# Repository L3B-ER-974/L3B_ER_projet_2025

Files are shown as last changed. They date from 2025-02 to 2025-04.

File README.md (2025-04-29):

# L3B_ER_projet_2025

Le but de notre projet est d'équipé le navire "SARL Réunion Formation Plongée" d'un ensemble d’appareils et de capteurs à la norme NMEA2000.

Projet2025

## Description du module et attendu final

Mon module c'est une carte avec un écran monté dessus relier avec un microcontroleur (ATMEGA328-16AU), un programmateur (HE10_6), une alimentation XL1509-5.0 (ce composant là va me permettre d'adapter le courant d'entré en 5V pour toute la carte), d'un MCP2551 et d'un MCP2515, d'un GX12 (c'est là que va arrivé les informations des capteurs), d'un AMS1117-3.3 (ce composant là c'est pour régulé la tension à 3,3 V pour l'écran), un connecteur embase droite pour voir les trames et enfin des diodes électroluminécantes (XL-3216SURC) pour voir les communications TX, RX et l'alimentation si ils sont tous bien connectés. Le MCP2551 et le MCP2515 vont tout les deux me permettre d'assurer la communication entre le microcontroleur et les capteurs et de garder temporairement les données des capteurs.

Ce qui est attendu au final, c'est que je dois concevoir une carte avec les composants marqués au-dessus, un écran multifonctions qui gère par derrière les trames NMEA2000 des capteurs et qui les affiches en clair sur l'écran.

<ins> **Exemple d'un écran multifonctions avec les relevés des capteurs  :**</ins>

   

<ins> **Exemple de carte à fabriqué :**</ins>



## Description des grandeurs d'entrée et de sortie 

Ma maquette, ce qu'il fait, c'est qu'il va recevoir les trames NMEA2000 des différents capteurs à l'entrée (Ils vont tous passer par le GX12), ils vont ensuite être filtrés et traités par mes composants MCP2515 et MCP2555. Ensuite, ces mêmes composants vont assurer la passerelle entre le microcontrôleur et les composants (BUS SPI). Ensuite, le microcontrôleur traite les données des différents capteurs et les envoie ensuite sous format de texte les valeurs des différents capteurs sur un écran LCD SPI (Un programme sera mis dans le microcontroleur pour traité les données des capteurs) .

## Description des composants constitutifs de l'unité 

Ecran LCD "SKU MAR2406 driver ILI9341" : 
 
 - Taille écran : 2.4 pouces (6,096 cm en diagonal )
 - Résolution : 320*240 pixel
 - Couleur : RGB 65k color
 - Communication : BUS SPI

Microprocesseur "ATMEGA328-16AU": 
 
 - Alimentation : 1.8 - 5.5 V
 - Plage de fréquence : 0 - 20 MHz
 - programmable en série USART
 - Possédent 32 broches au total
 - Limitation courant : 200 mA
 - Possédent l'interface SPI et 2-wire
 - Accepte jusqu'à 32 kbit les prè-programmes
 - Possédent une mémoire EEPROM qui garde l'information jusqu'a 1kbit lorsque la carte est éteint.

Composant "MCP2515" : 

 - Communication : CANH et CANL
 - Alimentation : 2.7 V - 5.5 V
 - Plage de température : -40 °C à + 85 °C
 - Interface SPI cadencé à 10 MHz

Composant "MCP2551" :
 
 - Communication : CANH et CANL
 - Alimentation : 4.5V - 5.5V
 - Tension continue pour CANH et CANL entre : -42 V et + 42 V
 - Plage de température : -55 °C et + 150 °C

Composant "XL1509-5.0" :

 -Tension de sortie régulé à : 5V (valeur typique)
 -Tension d'entré accepté : 4.5V - 40V
 -Oscillateur de fréquence : 150 khz (valeur typique)
 -Limite de courant : 4 A.

Composant "AMS1117-3.3" : 

- Régule la tension jusqu'à 5 V
- La tension d'entré maximun est 18 V
- La plage de température est compris entre -65 °C à 150 °C

Le protocole qui est utilisé c'est le protocole SIMNET et pour la communication c'est le BUS CAN. 

## Les diagrammes 

<ins> **Diagramme de cas d'utilisation :**</ins>

Diagramme_de_cas_utilisation

<ins> **Diagramme d'éxigence :**</ins>

Diagramme_exigence_Jean

<ins> **Diagramme de bloc interne :**</ins>

Diagramme_de_bloc_interne

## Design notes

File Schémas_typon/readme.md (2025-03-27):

# Description des composants utilisés

- [x] Réalisation du schéma structurel
   - Justification du choix des composants principaux

ATMEGA328-16AU : Nous avons choisir de prendre un ATMEGA328-16AU car la fréquence que fournit le composant (fournir jusqu'à 20 MHz) permet de faire tourner tout les autres composants. De plus, le composant est capable de gérer le BUS SPI.

XL1509-5.0 : Nous avons choisir ce régulateur de tensions là car la plage qu'on peut fournir à l'entré du composant s'éléve jusqu'à 40 V ce qui est plus convenable. De plus, le composant est capable de réguler la tension jusqu'à 5 V ce qui est convenable pour nos composant qui nécessite justement une plage compris entre 1 V et 5 V. 

AMS1117-3.3 : Nous avons choisir ce régulateur tensions pour l'écran LCD. En effet, nous avons choisir ce régulateur tensions car la tensions nécessaire au fonctionnement de l'écran LCD nécessite une tension de 3,3 V.Donc, aprés que le régulateur XL1509-5.0 est finir de régulé la tensions à 5 V, c'est au tour du composant AMS1117-3.3 de régulé à nouveau la tension à 3.3 V pour l'écran LCD qui ne peut encore là que accepter une tension de 3.3 V. 

MCP2551 : Nous avons choisir ce composant là car il va servir de passerelle entre le contrôleur CAN et le bus CAN, il va convertir les signaux logiques en signaux électriques pour adapter au BUS CAN.   

MCP2515 : Nous avons choisir ce composant là car il va gérer la gestion des messages CAN, filtrer les messages et il communiquera ces messages avec le microcontroleur en SPI. 

LCD3.5 UNO : Alors sur le schéma sctructurel nous avons prévues d'utiliser un écran LCD 2.4 pouces mais nous avons anticipé sur un écran LCD plus grand un 3.5 pouces. Pourquoi on a fait ça ? On a fait ça au cas ou si nous voulons un écran LCD plus grande. Nous avons choisir un LCD 2.4 pouces pour affiché les valeurs des capteurs sur un écran LCD (il va servir d'écran multifonctions). 
   
- [x] Réalisation du typon en double face
  
   - Contraintes de réalisation (dimension, largeur des pistes...)

Les contraintes de réalisation sont : 

  - Les pistes pour les composants d'alimentations qui fournit des tensions haute doivent faire 20mil sinon ils vont brûlé la carte (GX12, XL1509-5.0, les condensateurs et les inductances qui sont relier à ces alimentations ).
  - Les pistes pour le microcontroleur ATMEGA328-16AU doivent avoir une épaisseur de 15mil au maximun.
  - Les pistes doivent pas se croisé.
  - Limiter au maximun les trous sur les cartes (Les Vias).
  - Respecté un espacement entre les pastiles et les pistes qui passent entre les deux.
  - Priorisé les pistes du microcontroleurs en premier et les composants d'alimentations en dernier.
  - Ajouter deux plan de masse un au-dessus et un en-dessous de la carte.
  - Renseigné que la référence des composants (Exemple : R10, C15,U1) et pas le type ou les valeurs des composants (exemple : XL1509-5.0, 150 µF...)  car ce qui est important c'est qu'on voir la référence des composants quand la carte est finir (Voir image ci-dessous).
  - La référence des composants doivent être bien lisible et doivent avoir la même orientation exemple : "si une référence d'un composant est positionné horizontalement alors tout les autres références doivent être positionné pareillement pour facilité la visibilité ".  
  - Mettre les connecteurs au bord de la carte (Salea logic, GX12, ISP-PROG)
  - Il faut limité les angles droits des pistes. 

<ins>Carte de projet croix de pharmacie :</ins> 



Il faut que l'orientation des textes soient tous pareils. 

- [x] Édition des fichiers de constructions Gerber

L'édition qu'il y a eu sont : 
 
 - Les pistes que je devais reposiotionné. (déjà fait)
 - Les références des composants que je devais tous bien orientés. (déjà fait)
 - Les ajouts des plans de masses sur la partie au-dessus et en-dessous de la carte. (déjà fait)

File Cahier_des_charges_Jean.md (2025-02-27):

# L3B_ER_projet_2025

Le but de notre projet est d'équipé le navire "SARL Réunion Formation Plongée" d'un ensemble d’appareils et de capteurs à la norme NMEA2000.

Projet2025

## Description du module et attendu final

Le module que je dois concevoir c'est un écran multifonction qui affiche les mesures de l'anémomètre-girouette (la vitesse du vent ainsi que sa direction), la température, le débit et le niveau d'essence pour le moteur 1, le régime moteur et totalisateur horaire du moteur 2 et enfin la vitesse relative sur l'eau.

Ce qui est attendu au final c'est que je dois concevoir une carte fonctionnel qui affiche les mesures que j'ai cité au-dessus. 

<ins> **Exemple d'écran multifonction avec d'autre mesure  :**</ins>


 
<ins> **Exemple de carte à fabriqué :**</ins>



## Description des grandeurs d'entrée et de sortie 

Alors notre maquette va recevoir à l'entré le bus de données CAN, ensuite, ces données vont être traité par le microcontroleur puis ils vont être affiché par l'afficheur LCD 2.4inch en bus SPI. 

## Description des composants constitutifs de l'unité 

Ecran LCD "SKU MAR2406 driver ILI9341" : 
 
 - Taille écran : 2.4 pouces (6,096 cm en diagonal )
 - Résolution : 320*240 pixel
 - Couleur : RGB 65k color
 - Communication : BUS SPI

Microprocesseur "Atmega328": 
 
 - Alimentation : 1.8 - 5.5 V
 - Plage de fréquence : 0 - 20 MHz
 - programmable en série USART
 - Possédent 32 broches au total
 - Limitation courant : 200 mA

Composant "MCP2515" : 

 - Communication : CANH et CANL
 - Alimentation : 2.7 V - 5.5 V

Composant "MCP2551" :
 
 - Communication : CANH et CANL
 - Alimentation : 4.5V - 5.5V

Composant "XL1509-5.0" :

 -Tension de sortie régulé à : 5V (valeur typique)
 -Tension entré : 4.5V - 40V
 -Oscillateur de fréquence : 150 khz (valeur typique)
 -Limite de courant : 4 A.

Le protocole qui est utilisé c'est le protocole SIMNET et pour la communication c'est le BUS CAN. 

## Les diagrammes 

<ins> **Diagramme de cas d'utilisation :**</ins>

Diagramme_de_cas_utilisation

<ins> **Diagramme d'éxigence :**</ins>

Diagramme_exigence_Jean

<ins> **Diagramme de bloc interne :**</ins>

Diagramme_de_bloc_interne

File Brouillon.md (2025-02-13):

# Brouillon

Le langage s'appelle Markdown :

Liens : "https://docs.github.com/fr/get-started/writing-on-github/getting-started-with-writing-and-formatting-on-github/basic-writing-and-formatting-syntax"

Le # sert à définir le "Titre"
Le ## sert à définir le "Sous-titre"
Le ### sert à définir le "Sous-sous-titre"

Prise de note : 

- Le diagramme structurel est finis.
- Les diagrammes de cas d'utilisation, d'éxigence et bloc interne sont finis.

Diagramme de cas d'utilisation : 

Diagramme_de_cas_utilisation

Diagramme de cas d'éxigence : 

Diagramme_exigence_Jean

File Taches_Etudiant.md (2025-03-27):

# L3B_ER_projet_2025

## A- Présentation du module
- A-1- Description générale du module et attendu final
- A-2-Description des grandeurs d'entrée et de sortie
  - plage de variation attendue
  - précision attendue
  - Résultat attendu
- A-3- Description des composants constitutifs de l'unité
  - Caractéristique entrée-sortie 
  - plage de variation
  - précision, résolution, limitation
  - Type de bus
  - ports utilisés
  - alimentation et consommation
  - ...
- A-4- Mise à jour des documentations techniques essentielles (extraits utiles ou résumé)

## B- Diagrammes SYSML
- Diagramme des cas d'utilisation
- Diagramme d'exigence
- Diagramme de bloc interne

## C- Schémas
- Schéma structurel
- Justification des composants choisis
- Typon
- Nomenclature
- Fichiers Gerbers

## D- Programmation et test
- Réalisation d'un ou plusieurs codes de test unitaire
- Réalisation du programme final sur prototype
- Ajout des commentaires et documentation aux programmes
- Validation du programme principal

## E- Module final
- Réalisation de la carte
- Protocoles de test : tests et mesures sur la carte
- Validation du fonctionnement de la carte
- Rédaction d'un cahier de recette simplifié
- Intégration du module au projet global

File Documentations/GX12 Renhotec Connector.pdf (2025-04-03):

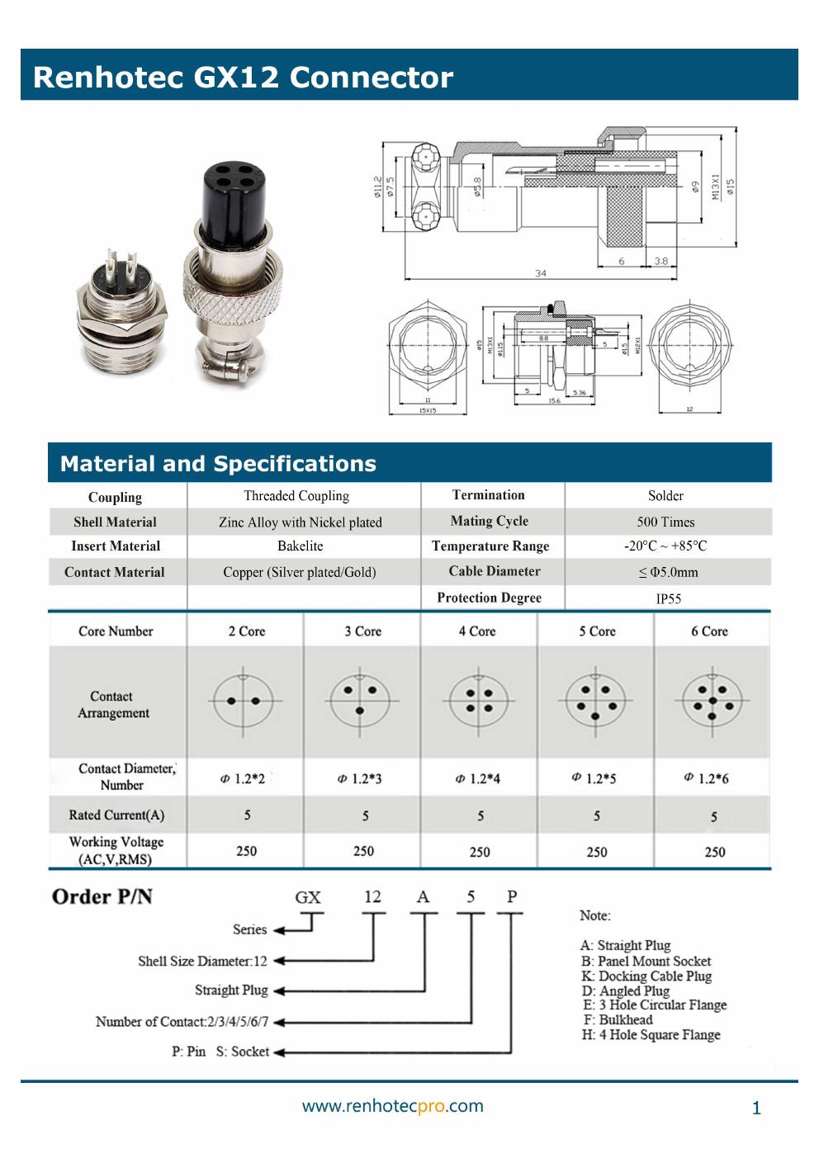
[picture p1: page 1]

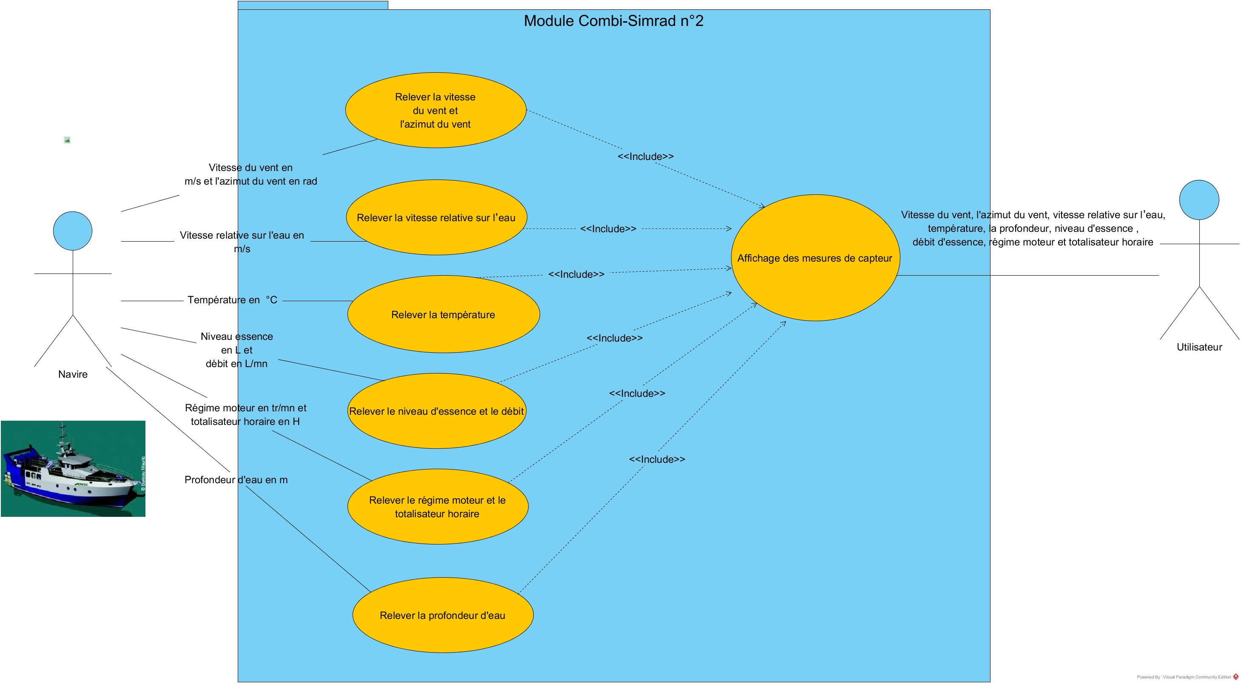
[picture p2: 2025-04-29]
Les diagrammes/Diagramme_de_cas_utilisation.jpg

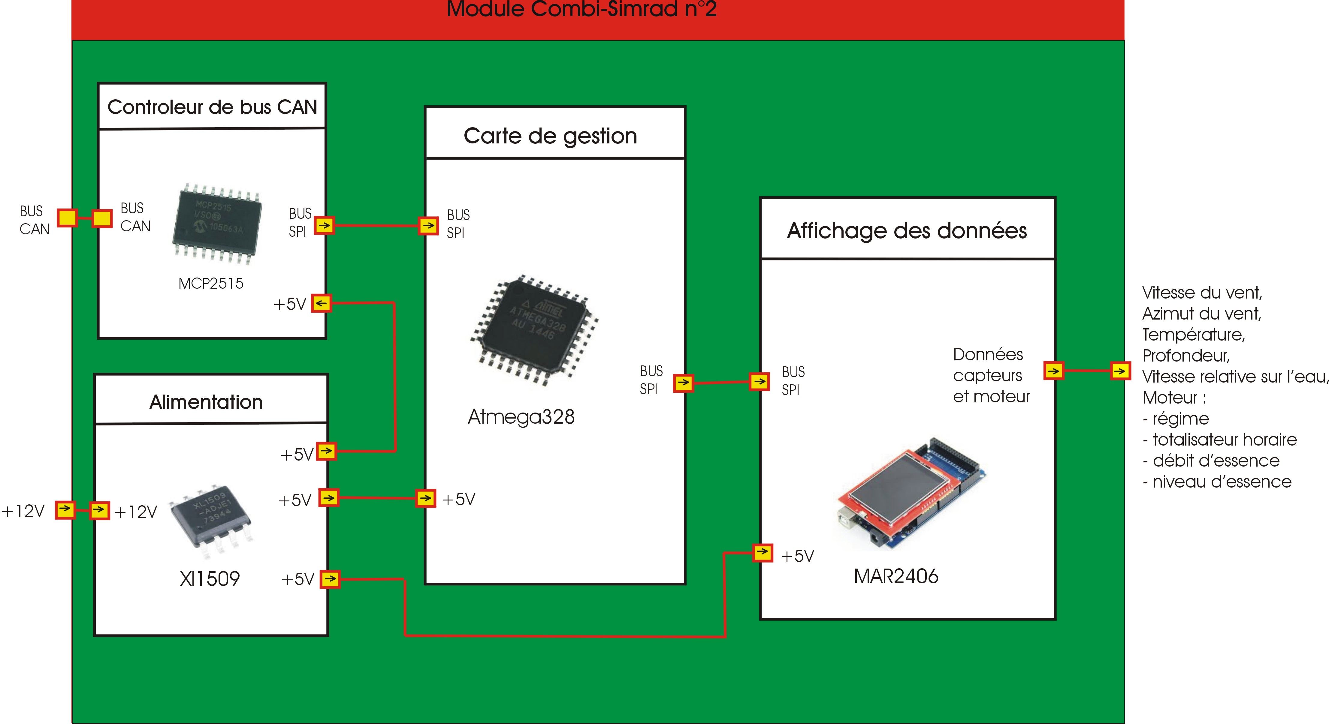
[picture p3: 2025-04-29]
Les diagrammes/Diagramme_de_bloc_interne.JPG

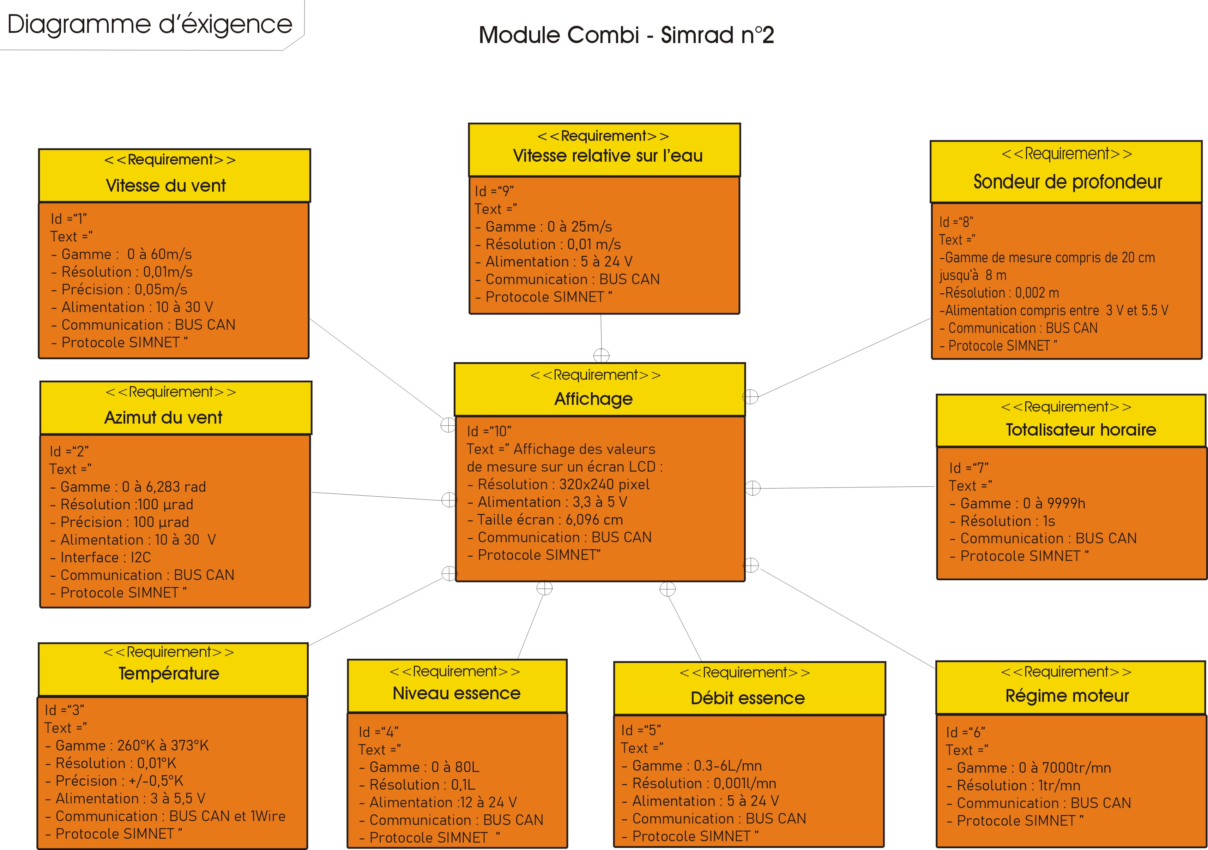
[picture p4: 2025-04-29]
Les diagrammes/Diagramme_exigence_Jean.JPG

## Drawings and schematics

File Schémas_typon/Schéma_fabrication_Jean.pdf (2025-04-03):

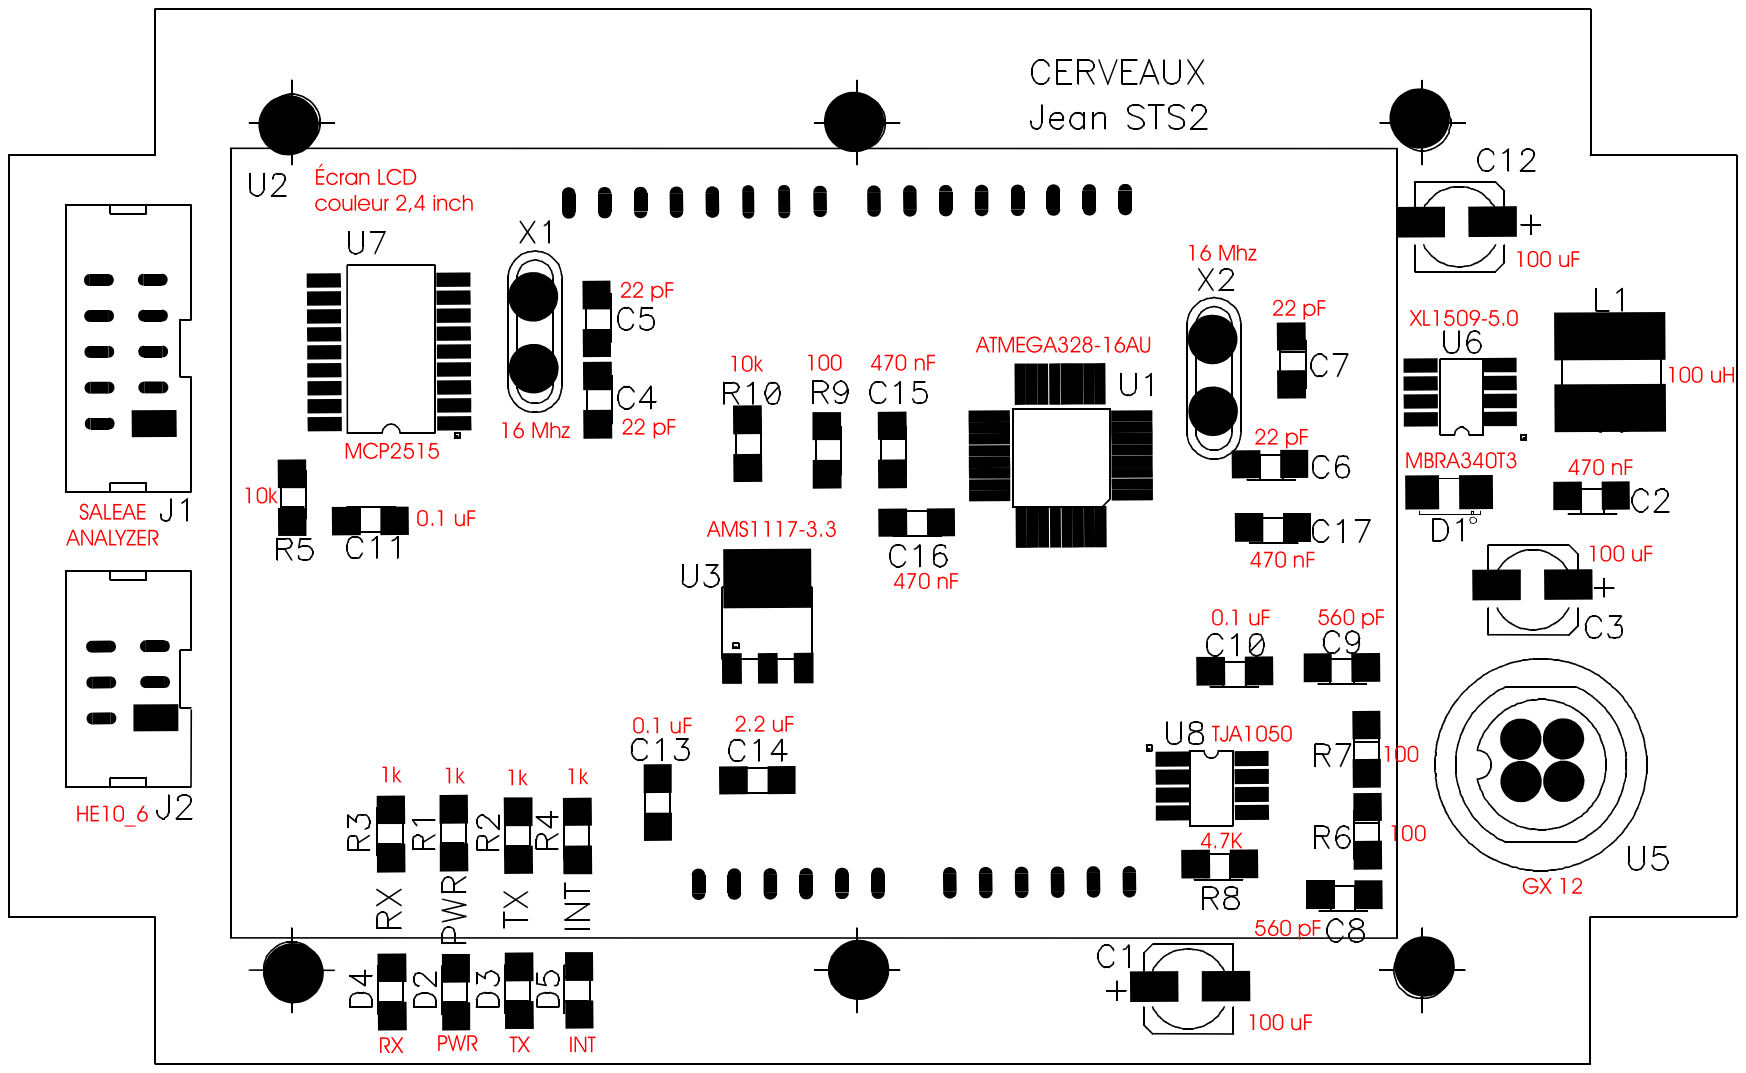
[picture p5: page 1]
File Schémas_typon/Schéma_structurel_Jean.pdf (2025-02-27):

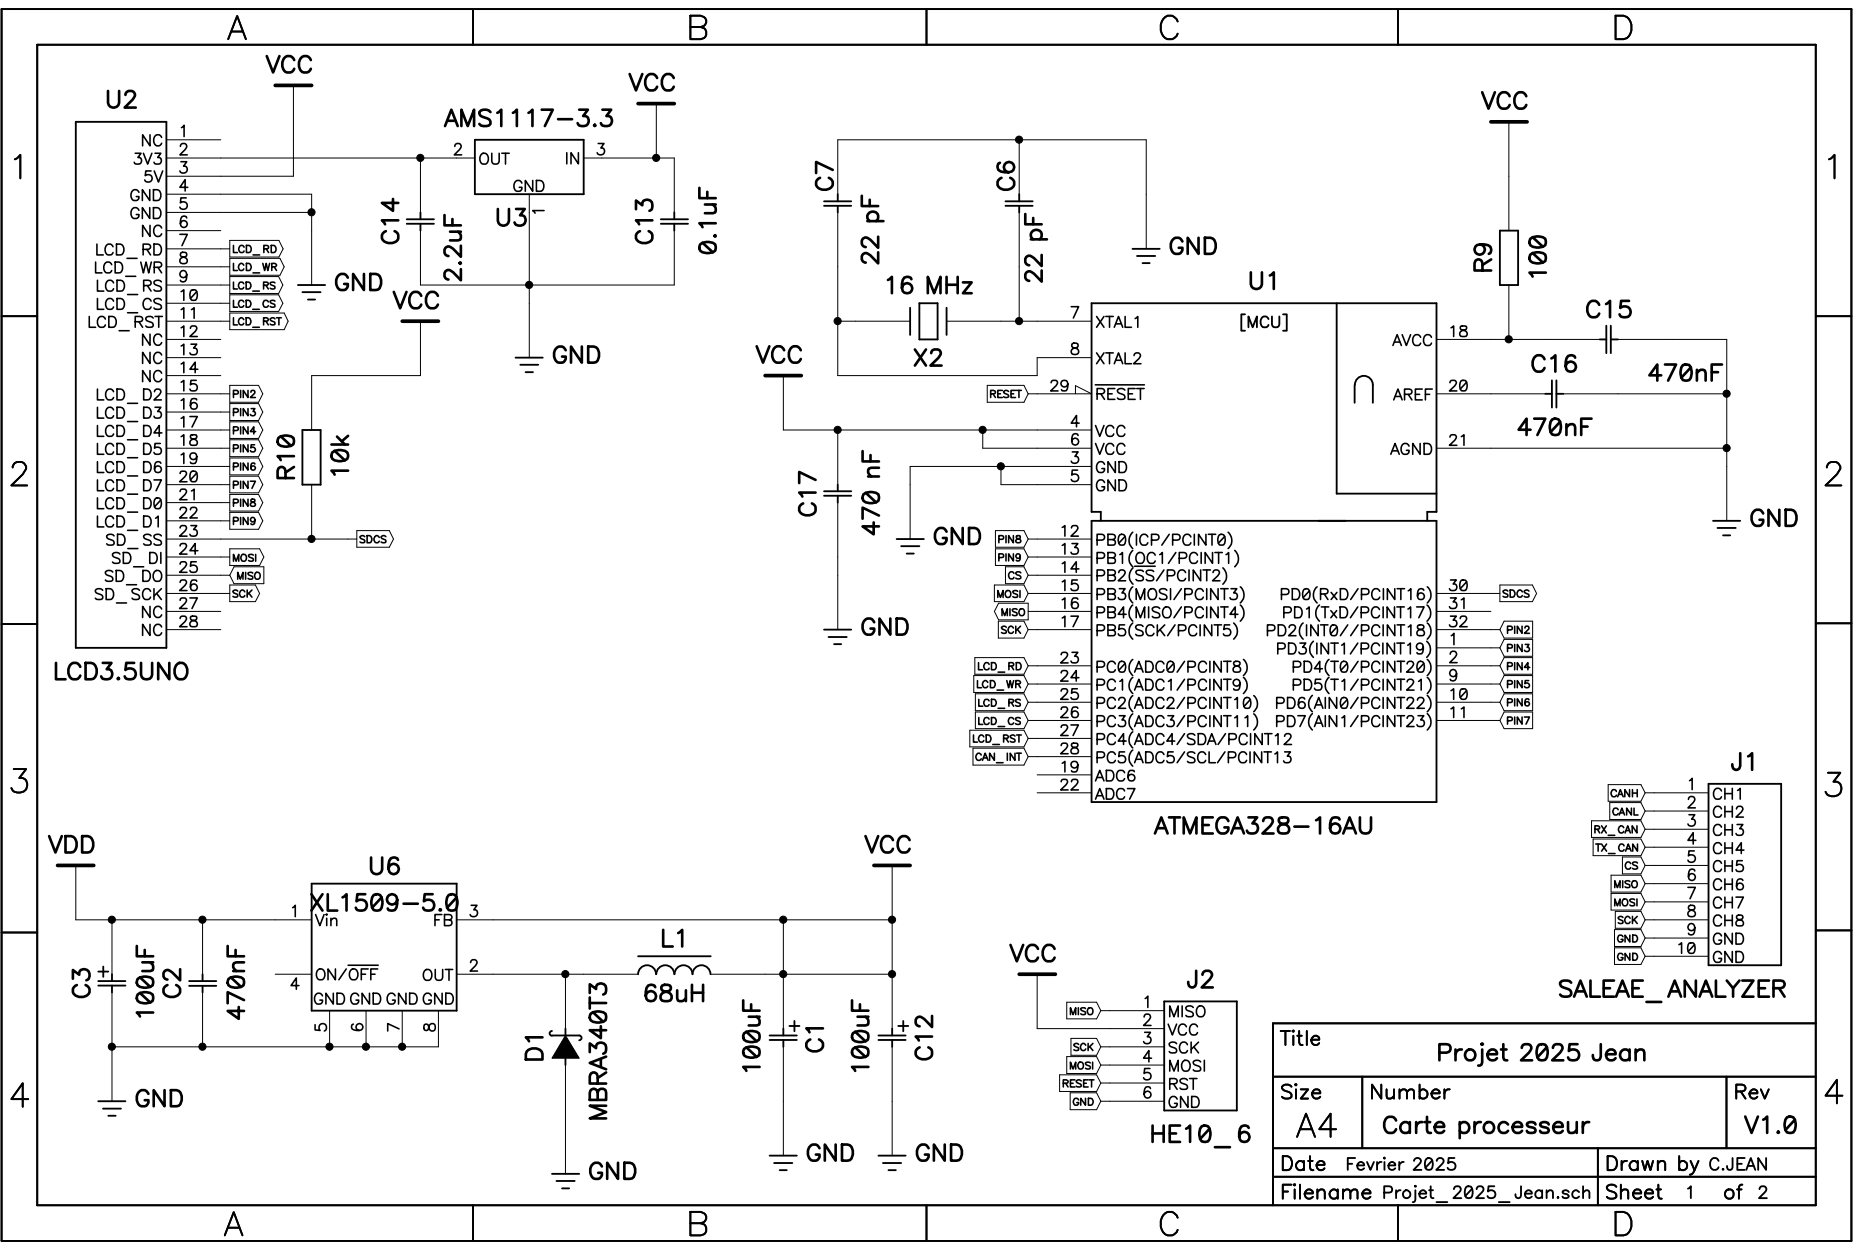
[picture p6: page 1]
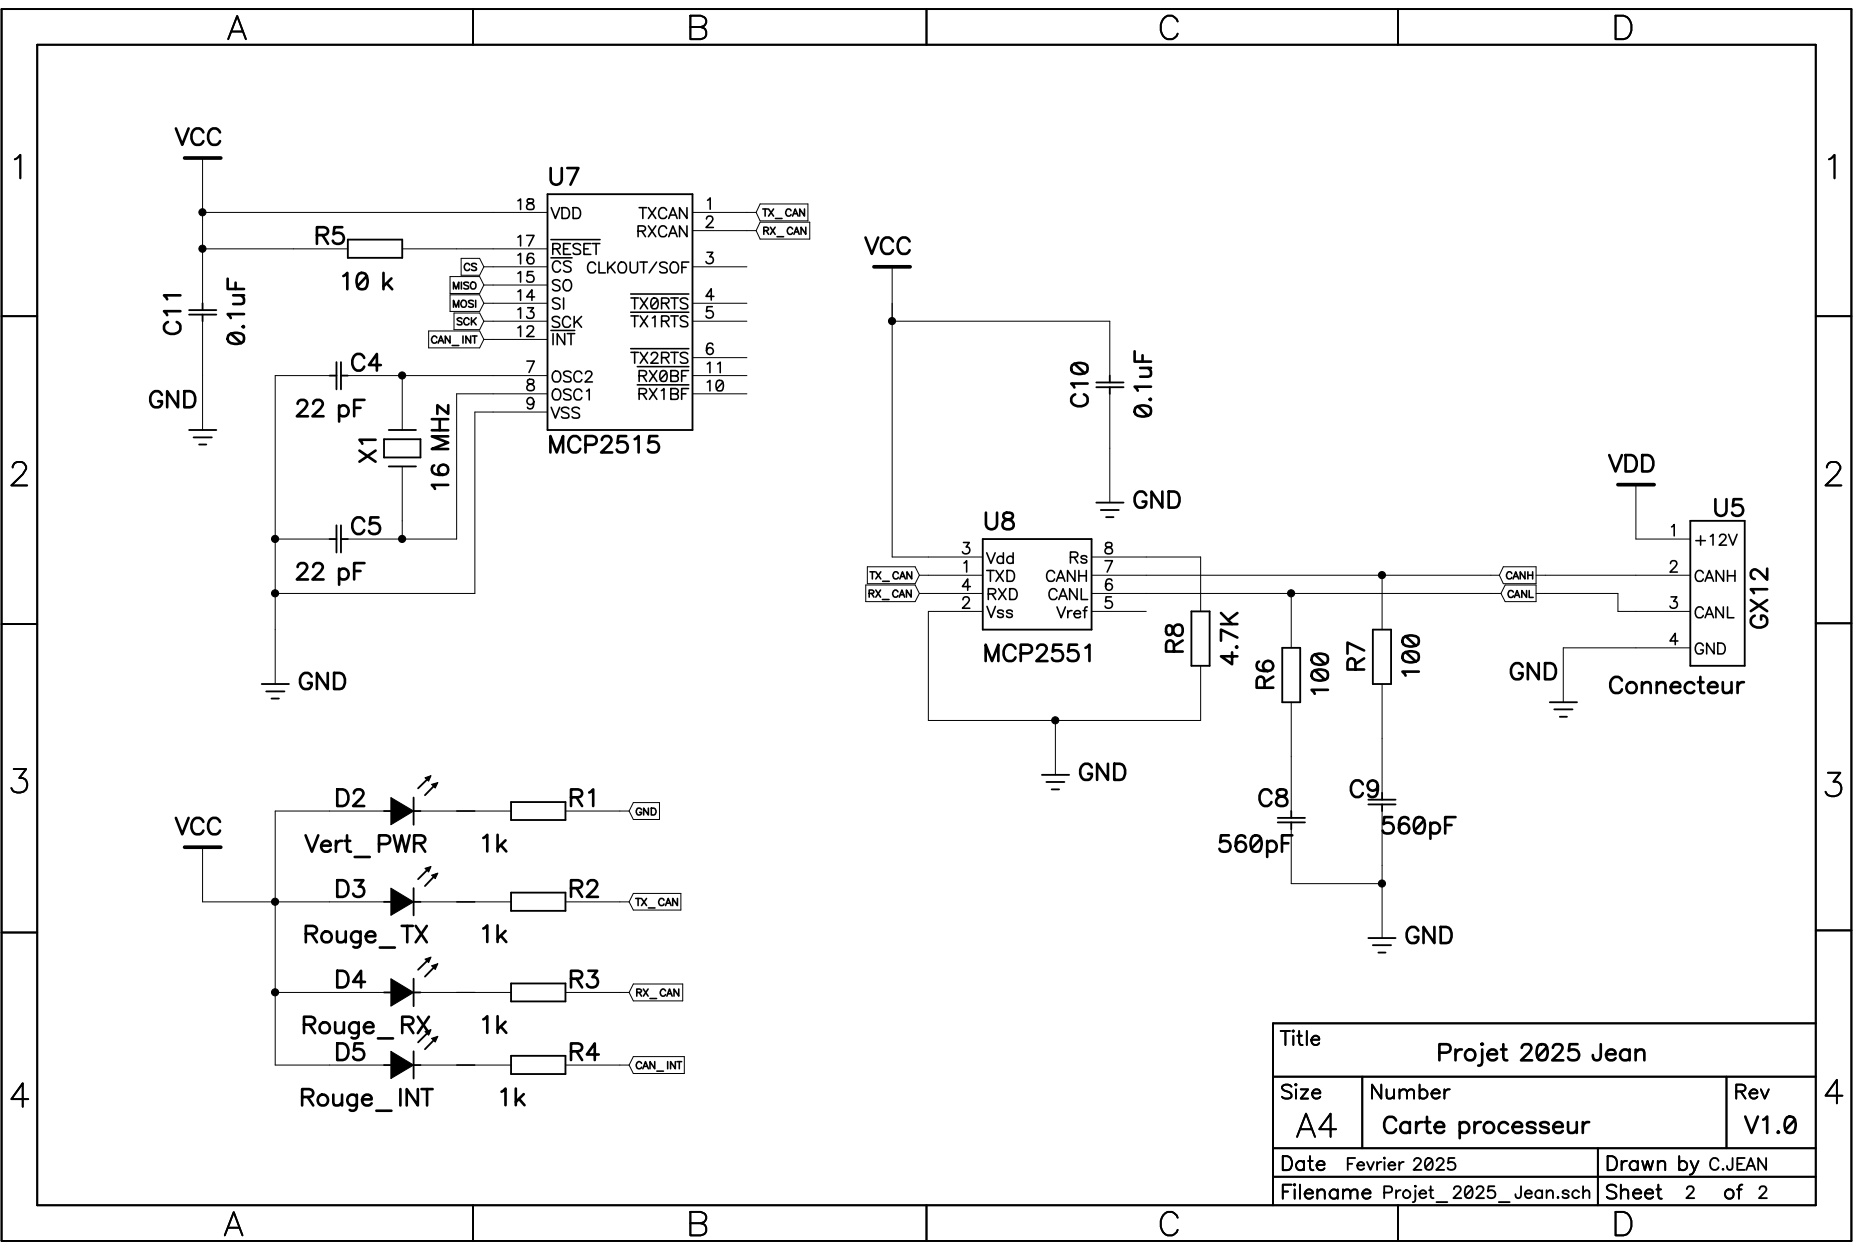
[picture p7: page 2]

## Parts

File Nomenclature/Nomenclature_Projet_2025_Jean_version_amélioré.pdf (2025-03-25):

Qu. | Repère | Désignation | Valeur / Réference | Précision / Equivalent | Boitier | Fabricant | Fournisseur | Réf. Fournisseur | Conditionnement | Prix condit. | Prix unitaire | Prix total
1 | U3 | Régulateur de tension fixe | AMS1117-3.3 | | SOT-223 | EVVO | Digi-Key | 5272-AMS1117-3.3TR-ND | 2500 | 320,68 | 0,13 | 0,13
1 | U1 | Microprocesseur | ATMEGA328-16AU | | 32-TQFP | Microship technology | Digi-Key | ATMEGA328-AU-ND | 100 | 191,63 | 1,92 | 1,92
4 | C4,C5,C6,C7 | Condensateur céramique | 22 pF | ± 20% | 1206 | KEMET | Digi-Key | 399-C1206C220M5GACTUTR-ND | 4000 | 182,16 | 0,05 | 0,18
4 | C17, C2, C16, C15 | Condensateur céramique | 470 nF | ± 20% | 1206 | Cal-Chip Electronics, Inc | Digi-Key | 4713-GMC31X7R474M50NTTR-ND | 3000 | 170,13 | 0,06 | 0,23
2 | C8,C9 | Condensateur céramique | 560 pF | ± 20% | 1206 | KEMET | Digi-Key | 399-C1206C561M1HACTUTR-ND | 4000 | 113,56 | 0,03 | 0,06
3 | C3,C1,C12 | Condensateur céramique | 100 µF | ± 20% | 2220 l | Cal-Chip Electronics, Inc | Digi-Key | 4713-GMC55X5R107M10NTTR-ND | 500 | 497,75 | 1,00 | 2,99
3 | C10,C11,C13 | Condensateur céramique | 0,1 µF | ± 20% | 1206 | Cal-Chip Electronics, Inc | Digi-Key | 4713-GMC31X7R104M50NTTR-ND | 4000 | 98,2 | 0,02 | 0,07
1 | C14 | Condensateur céramique | 2.2 µF | ± 20% | 1206 l | Cal-Chip Electronics, Inc | Digi-Key | 4713-GMC31X7R225M50NTTR-ND | 2000 | 152,90 | 0,08 | 0,08
1 | U5 | Connecteur circulaire 4 points | GX12 | | 12 mm | Olimex LTD | Digi-Key | 1188-CONNECTOR-GX12-4-ND | 1 | 1,79 | 1,79 | 1,79
1 | J2 | Connecteur embase Trou traversant 6 contacts | HE10_6 | | | Sullins Connector Solutions | Digi-Key | SBH11-PBPC-D03-ST-BK-ND | 1000 | 294,31 | 0,29 | 0,29
1 | U2 | Écran graphique TFT RVB 2,4 inch | LCD 2,4 UNO | | | Adafruit Industries LLC | Digi-Key | 1528-1471-ND | 1 | 28,55 | 28,55 | 28,55
4 | D2 ,D3 , D4 ,D5 | Diode électroluminescente | LED_CMS | | 1206 | XINGLIGHT | Digi-Key | 5962-XL-3216SURCTR-ND | 3000 | 21,84 | 0,01 | 0,03
1 | D1 | Diode zener | MBRA340T3 | | DO-214AC | ONSEMI | Farnell | 1431078 | 5 | 0,646 | 0,13 | 0,13
1 | U7 | CAN bus Contrôleur CAN 2.0 SPI | MCP2515 | | 18-SOIC | Microchip Technology | Digi-Key | MCP2515-I/SO-ND | 1 | 2,33 | 2,33 | 2,33
1 | U8 | Émetteur-récepteur 1/1 Semi CANbus | MCP2551 | | 8-SOIC | Microchip Technology | Digi-Key | MCP2551-I/SN-ND | 100 | 106,07 | 1,06 | 1,06
2 | X1, X2 | Quartz 16 Mhz | 16 Mhz | | | ECS Inc. | Digi-Key | XC1282TR-ND | 1000 | 186,48 | 0,19 | 0,37
4 | R1, R2, R3, R4 | Résistance | 1 kΩ | ± 5% | 1206 | Stackpole Electronics Inc | Digi-Key | RMCF1206JT1K00TR-ND | 5000 | 21,1 | 0,00 | 0,02
1 | R8 | Résistance | 4,7 kΩ | ± 5% | 1206 | Stackpole Electronics Inc | Digi-Key | RMCF1206JT4K70TR-ND | 5000 | 21,1 | 0,00 | 0,00
2 | R5, R10 | Résistance | 10 kΩ | ± 5% | 1206 | Stackpole Electronics Inc | Digi-Key | RMCF1206JT10K0TR-ND | 5000 | 21,1 | 0,00 | 0,01
3 | R6 , R7 , R9 | Résistance | 100 Ω | ± 5% | 1206 | Stackpole Electronics Inc | Digi-Key | RMCF0603JT100RTR-ND | 5000 | 11,1 | 0,00 | 0,01
1 | J1 | Connecteur embase Trou Traversant 10 positions | SALEAE_ANALYZER | | | On shore technology Inc, | Digi-Key | ED1543-ND | 260 | 44,15 | 0,17 | 0,17
1 | U6 | Abaisseur de tension Régulateur à découpage IC Positif Réglable 4,8V 1 Sortie 3A | XL1509-5.0 | | 8-SOP | UMW | Digi-Key | 4518-XL1509-5.0TR-ND | 2500 | 689,35 | 0,28 | 0,28
1 | L1 | Inductance | 68 µH | | 1616 | TDK Corporation | Digi-Key | 445-VLS4020CX-680M-HTR-ND | 1000 | 160,52 | 0,16 | 0,16
1 | | Circuit imprimé 118*72 mm | | | | PCBWAY | PCBWAY | | 5 | 46,71 | 9,34 | 9,34
| | | | | | | | | | Total | | 50,19
